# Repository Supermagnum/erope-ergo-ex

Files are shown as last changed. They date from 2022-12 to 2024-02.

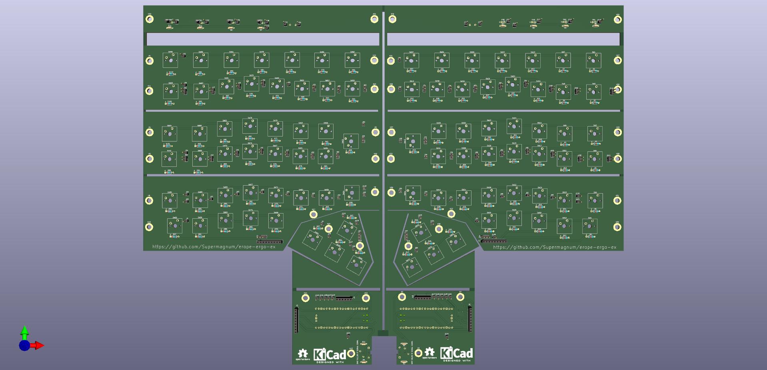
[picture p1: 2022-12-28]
Europe-flex.jpg

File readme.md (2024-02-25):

# Europe-ergo
A 94 key ergonomic,split keyboard, panelized.
Its powered by 2X Raspberry pico and linked with two TRRS jacks.
It uses tht components.

The reset switches, TRRS jacks and raspberry pico's  goes on the reverse side of the Pcb's. 

or:
http://www.keyboard-layout-editor.com/#/gists/50db7ea7b0832342d4c734eb985ec16b

The L1/L2 button is to change from  Norwegian QWERTY to Norwegian Dvorak.

Keycaps:
https://github.com/Supermagnum/Europe-ergo/blob/main/keycaps.jpg

PCBway:
<a href="https://www.pcbway.com/project/shareproject/Europe_ergo_2951aba6.html">PCB from PCBWay</a>

Aisler:
https://aisler.net/p/NEFSAHWJ

Firmware:
[https://github.com/Supermagnum/Europe-ergo/tree/main/Europe_ergo_firmware/europe_ergo](https://github.com/Supermagnum/Europe-ergo/tree/main/ergo-firmware/europe_ergo)

Picture:
https://github.com/Supermagnum/erope-ergo-ex/blob/main/Europe-flex.jpg

All mechanical blueprints as pdf files can be exported from the Freecad file.
Freecad can be found for free here:
https://www.freecadweb.org/

Vial:

https://get.vial.today/

PWM1 to PWM 4 controls LED's ( ON/OFF) based by the active layer, and also caps lock and scroll lock active.

Those and the electrical diagram can be found here:
https://github.com/Supermagnum/Europe-ergo/blob/main/Europe-ergo-PCB/schema/Europe-ergo.pdf
The right side has identical outputs for PWM.

Cherry MX switches should fit the PCB'S.

---------
To do:
Make the cutouts closer to the top and bottoms of the double rows.
Make pcb holders in kicad.
Reduce the number of two pin connectors, and label the connections on the Pcb's.

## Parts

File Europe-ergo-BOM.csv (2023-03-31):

Source: | /mnt/b955457f-512b-4f44-a0f7-8e5f2b78aba2/Europe-ergo/Europe-ergo-PCB/Europe-ergo.kicad_sch
Date: | fr. 31. mars 2023 kl. 15.45 +0200
Tool: | Eeschema 7.0.1-3b83917a11~172~ubuntu22.04.1
Generator: | /usr/share/kicad/plugins/bom_csv_grouped_by_value.py
Component Count: | 234
Collated Components:
Item | Qty | Reference(s) | Value | LibPart | Footprint | Datasheet | DNP | Field4
1 | 94 | D1, D2, D3, D4, D5, D6, D7, D8, D9, D10, D11, D12, D13, D14, D15, D16, D17, D18, D19, D20, D21, D22, D23, D24, D25, D26, D27, D28, D29, D30, D33, D34, D35, D44, D45, D46, D47, D48, D49, D50, D51, D52, D53, D54, D55, D56, D57, D58, D59, D60, D61, D62, D63, D64, D65, D66, D67, D68, D69, D70, D71, D72, D73, D74, D75, D76, D77, D78, D79, D80, D81, D82, D83, D84, D85, D86, D87, D88, D89, D90, D91, D92, D93, D94, D95, D96, D97, D98, D99, D100, D101, D102, D103, D104 | 1N4148 | Diode:1N4148 | Diode_THT:D_DO-35_SOD27_P7.62mm_Horizontal | https://assets.nexperia.com/documents/data-sheet/1N4148_1N4448.pdf
2 | 6 | D31, D32, D36, D37, D38, D43 | LTL-4233 | Device:LED | Diode_THT:D_A-405_P2.54mm_Vertical_AnodeUp | ~
3 | 4 | D39, D40, D41, D42 | LTL-4233 | Device:LED | Diode_THT:D_DO-34_SOD68_P2.54mm_Vertical_KathodeUp | ~
4 | 16 | H1, H2, H3, H4, H5, H6, H7, H8, H9, H10, H11, H12, H13, H14, H15, H16 | MountingHole_Pad | Mechanical:MountingHole_Pad | MountingHole:MountingHole_4.3mm_M4_DIN965_Pad | ~
5 | 2 | J1, J2 | SJ-435107 | Connector:Conn_01x04_Male | sj-conn:CUI_SJ-435107 | ~
6 | 10 | R1, R2, R3, R4, R5, R6, R7, R8, R9, R10 | 330 | Device:R | Resistor_THT:R_Axial_DIN0204_L3.6mm_D1.6mm_P5.08mm_Horizontal | ~
7 | 4 | R11, R12, R13, R14 | 4.7K | Device:R | Resistor_THT:R_Axial_DIN0204_L3.6mm_D1.6mm_P5.08mm_Horizontal | ~
8 | 41 | SW1, SW2, SW3, SW4, SW5, SW6, SW7, SW18, SW19, SW20, SW21, SW22, SW23, SW24, SW34, SW35, SW36, SW37, SW38, SW39, SW50, SW51, SW52, SW53, SW54, SW55, SW64, SW65, SW66, SW67, SW68, SW69, SW71, SW81, SW82, SW83, SW84, SW85, SW86, SW87, SW88 | MX1A-G1NN | pcb-flat-left-rescue:MX-NO-LED-keyboard2-pcb-flat-right-rescue | Button_Switch_Keyboard:SW_Cherry_MX_1.00u_PCB |  |  | arrow-up
9 | 41 | SW8, SW9, SW10, SW11, SW12, SW13, SW14, SW25, SW26, SW27, SW28, SW29, SW30, SW31, SW42, SW43, SW44, SW45, SW46, SW47, SW56, SW57, SW58, SW59, SW60, SW61, SW72, SW74, SW75, SW76, SW77, SW78, SW79, SW89, SW90, SW91, SW92, SW93, SW94, SW95, SW96 | MX1A-G1NN | pcb-flat-right-rescue:MX-NO-LED-keyboard2 | Button_Switch_Keyboard:SW_Cherry_MX_1.00u_PCB |  |  | arrow-up
10 | 2 | SW15, SW16 | 800SP9B6M2RE | Switch:SW_Push | switch:switch_P5.08mm | ~
11 | 6 | SW17, SW33, SW40, SW49, SW63, SW70 | MX1A-G1NN | pcb-flat-left-rescue:MX-NO-LED-keyboard2-pcb-flat-right-rescue | Button_Switch_Keyboard:SW_Cherry_MX_1.50u_PCB
12 | 6 | SW32, SW41, SW48, SW62, SW73, SW80 | MX1A-G1NN | pcb-flat-right-rescue:MX-NO-LED-keyboard2 | Button_Switch_Keyboard:SW_Cherry_MX_1.50u_PCB
13 | 2 | U1, U2 | SC0915 | MCU_RaspberryPi_and_Boards:Pico | MCU_RaspberryPi_and_Boards:RPi_Pico_SMD_TH

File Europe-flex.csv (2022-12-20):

Source: | /home/haaken/98keys-ergo.git/trunk/98keys-split-pcb/98keys-split-pcb.kicad_sch
Date: | lø. 03. des. 2022 kl. 18.18 +0100
Tool: | Eeschema 6.0.9-8da3e8f707~117~ubuntu20.04.1
Generator: | /usr/share/kicad/plugins/bom_csv_grouped_by_value_with_fp.py
Component Count: | 230
Ref | Qnty | Value | Cmp name | Footprint | Description | Vendor
D1, D2, D3, D4, D5, D6, D7, D8, D9, D10, D11, D12, D13, D14, D15, D16, D17, D18, D19, D20, D21, D22, D23, D24, D25, D26, D27, D28, D29, D30, D31, D32, D33, D34, D35, D36, D37, D38, D39, D40, D41, D42, D43, D44, D45, D46, D47, D56, D57, D58, D59, D60, D61, D62, D63, D64, D65, D66, D67, D68, D69, D70, D71, D72, D73, D74, D75, D76, D77, D78, D79, D80, D81, D82, D83, D84, D85, D86, D87, D88, D89, D90, D91, D92, D93, D94, D95, D96, D97, D98, D99, D100, D101, D102, | 94 | 1N4148 | 1N4148 | Diode_THT:D_DO-35_SOD27_P7.62mm_Horizontal | 100V 0.15A standard switching diode, DO-35
D48, D49, D50, D51, | 4 | LED | LED | Diode_THT:D_DO-34_SOD68_P2.54mm_Vertical_KathodeUp | Light emitting diode
D52, D53, D54, D55, | 4 | LTL-4233 | LED | Diode_THT:D_A-405_P2.54mm_Vertical_AnodeUp | Light emitting diode
H1, H2, H3, H4, H5, H6, H7, H8, H9, H10, H11, H12, H13, H14, H15, H16, | 16 | MountingHole_Pad | MountingHole_Pad | MountingHole:MountingHole_4.3mm_M4_DIN965_Pad | Mounting Hole with connection
J1, | 1 | Conn_01x04_Male/I2C | Conn_01x04_Male | Connector_Audio:Jack_3.5mm_CUI_SJ1-43514_Horizontal | Generic connector, single row, 01x04, script generated (kicad-library-utils/schlib/autogen/connector/)
J2, | 1 | Conn_01x04_Male | Conn_01x04_Male | Connector_Audio:Jack_3.5mm_CUI_SJ1-43514_Horizontal | Generic connector, single row, 01x04, script generated (kicad-library-utils/schlib/autogen/connector/)
R1, R2, R4, R6, R7, R8, R10, R12, | 8 | 330 | R | Resistor_THT:R_Axial_DIN0204_L3.6mm_D1.6mm_P5.08mm_Horizontal | Resistor
R3, R5, R9, R11, | 4 | 4.7K | R | Resistor_THT:R_Axial_DIN0204_L3.6mm_D1.6mm_P5.08mm_Horizontal | Resistor
SW1, SW6, SW7, SW8, SW9, SW10, SW11, SW12, SW13, SW14, SW15, SW16, SW17, SW18, SW19, SW20, SW21, SW22, SW23, SW24, SW25, SW26, SW27, SW28, SW29, SW30, SW31, SW32, SW33, SW34, SW35, SW36, SW37, SW38, SW39, SW40, SW41, SW42, SW45, SW46, SW47, SW50, SW51, SW52, SW55, SW56, SW57, SW58, SW59, SW60, SW61, SW62, SW63, SW64, SW65, SW66, SW67, SW68, SW69, SW70, SW71, SW72, SW73, SW74, SW75, SW76, SW77, SW78, SW79, SW80, SW81, SW82, SW83, SW84, SW85, SW86, SW87, SW88, SW89, SW90, SW92, SW96, | 82 | MX-NO-LED | MX-NO-LED-keyboard2-pcb-flat-right-rescue | Button_Switch_Keyboard:SW_Cherry_MX_1.00u_PCB
SW2, SW3, SW4, SW5, SW43, SW44, SW53, SW54, SW91, SW93, SW94, SW95, | 12 | MX-NO-LED | MX-NO-LED-keyboard2-pcb-flat-right-rescue | Button_Switch_Keyboard:SW_Cherry_MX_1.50u_PCB
SW48, SW49, | 2 | SW_Push | SW_Push | switch:switch_P5.08mm | Push button switch, generic, two pins
U1, U2, | 2 | Pico | Pico | MCU_RaspberryPi_and_Boards:RPi_Pico_SMD_TH

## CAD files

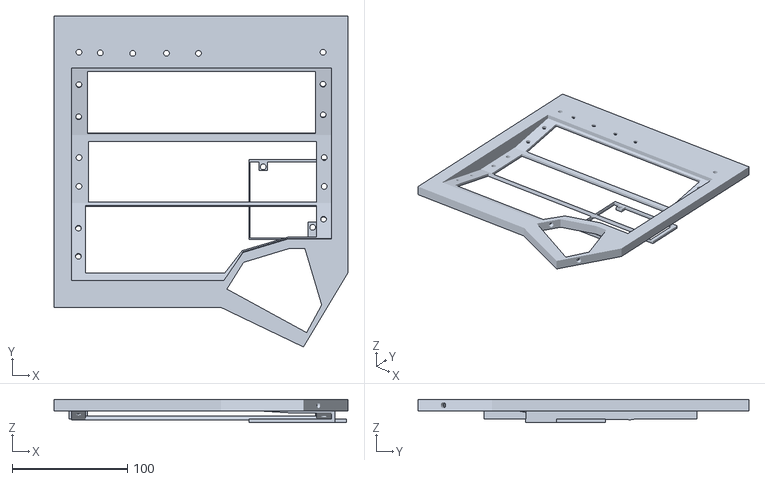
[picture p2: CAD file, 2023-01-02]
Mechanical/holder-left.stl
255.0 x 287.5 x 20.0

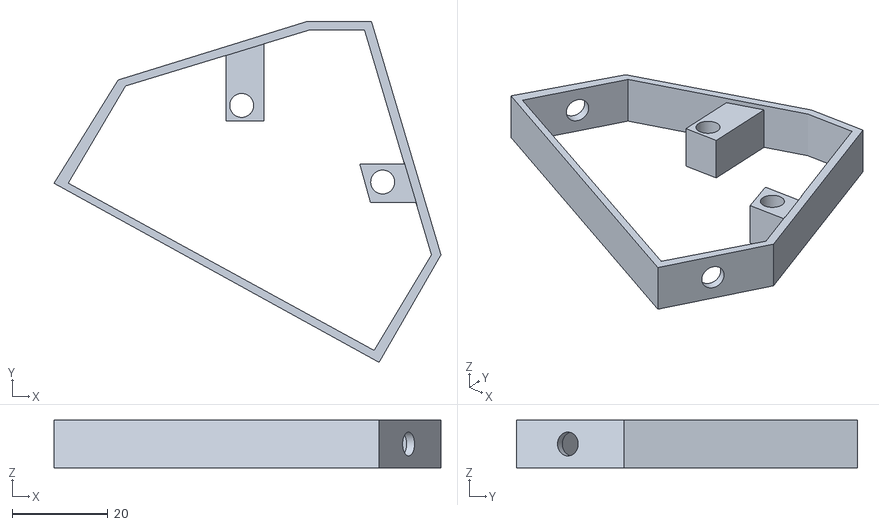
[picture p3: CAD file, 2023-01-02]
Mechanical/holder-thumb.stl
81.0 x 71.3 x 10.0

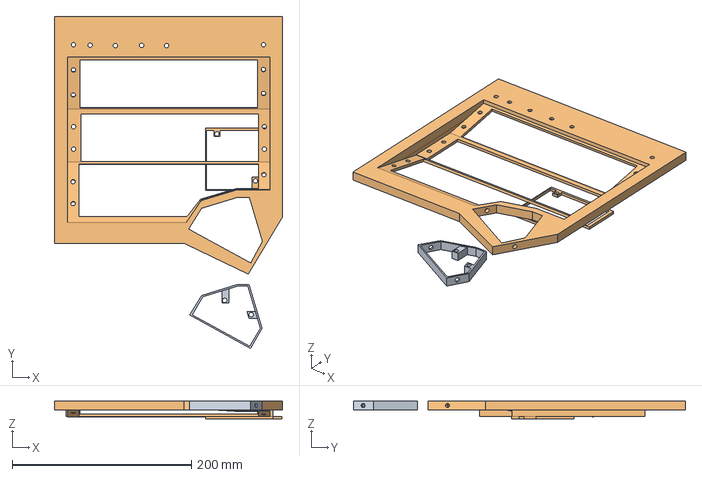
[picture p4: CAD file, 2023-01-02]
Mechanical/holder.FCStd
255.0 x 370.5 x 20.0 mm

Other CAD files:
Mechanical/holder-right.stl
Mechanical/holders.blend

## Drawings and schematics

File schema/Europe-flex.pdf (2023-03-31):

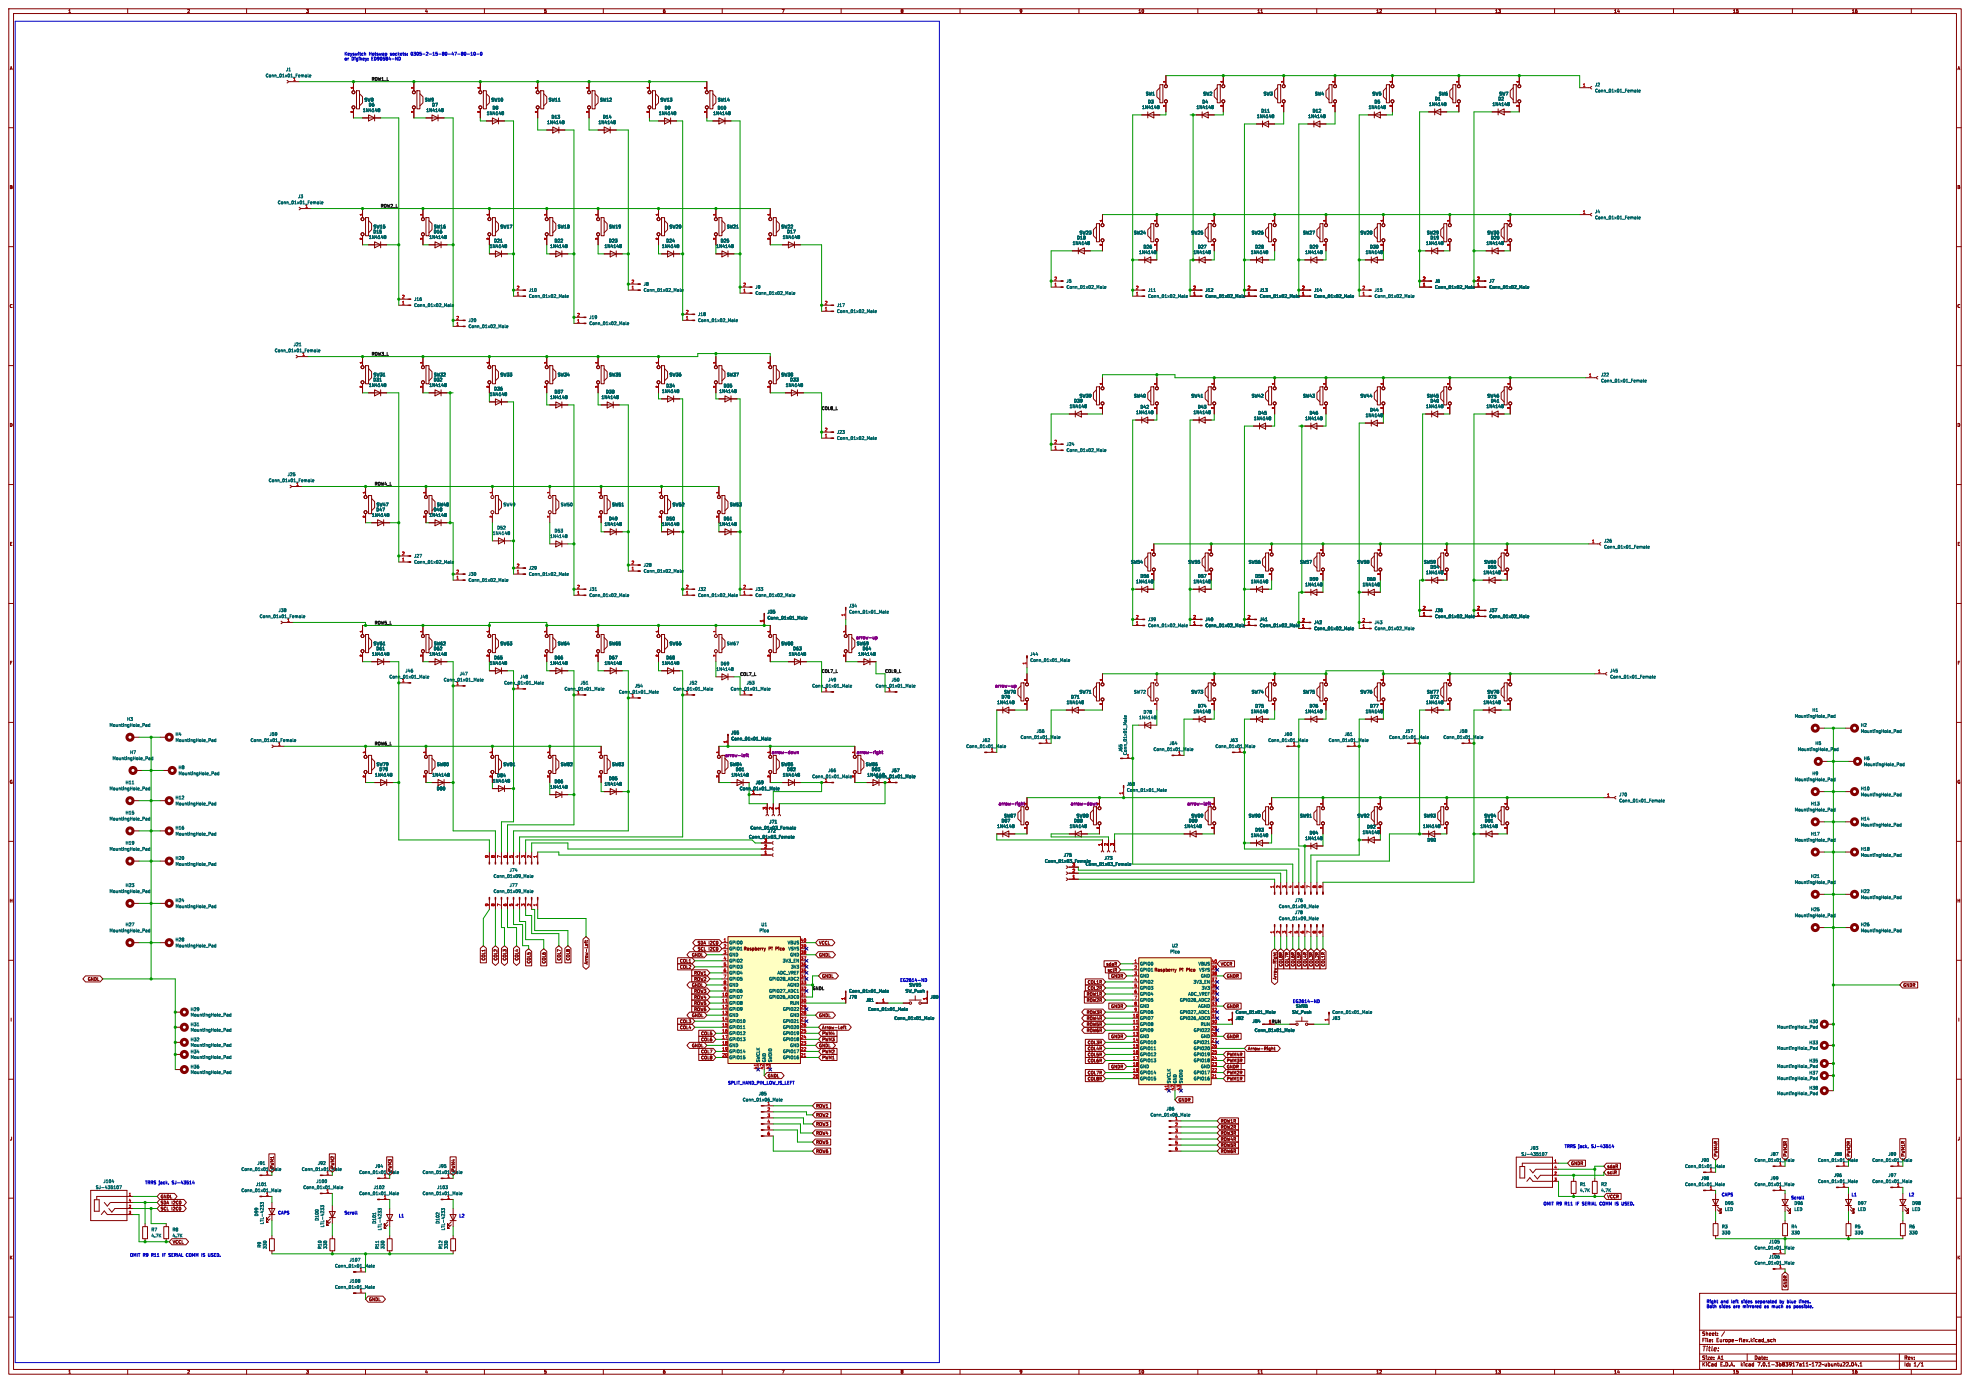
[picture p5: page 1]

PWM3 PWM1 PWM2 GNDL PWM4 GNDL VCCL GNDL PWM3

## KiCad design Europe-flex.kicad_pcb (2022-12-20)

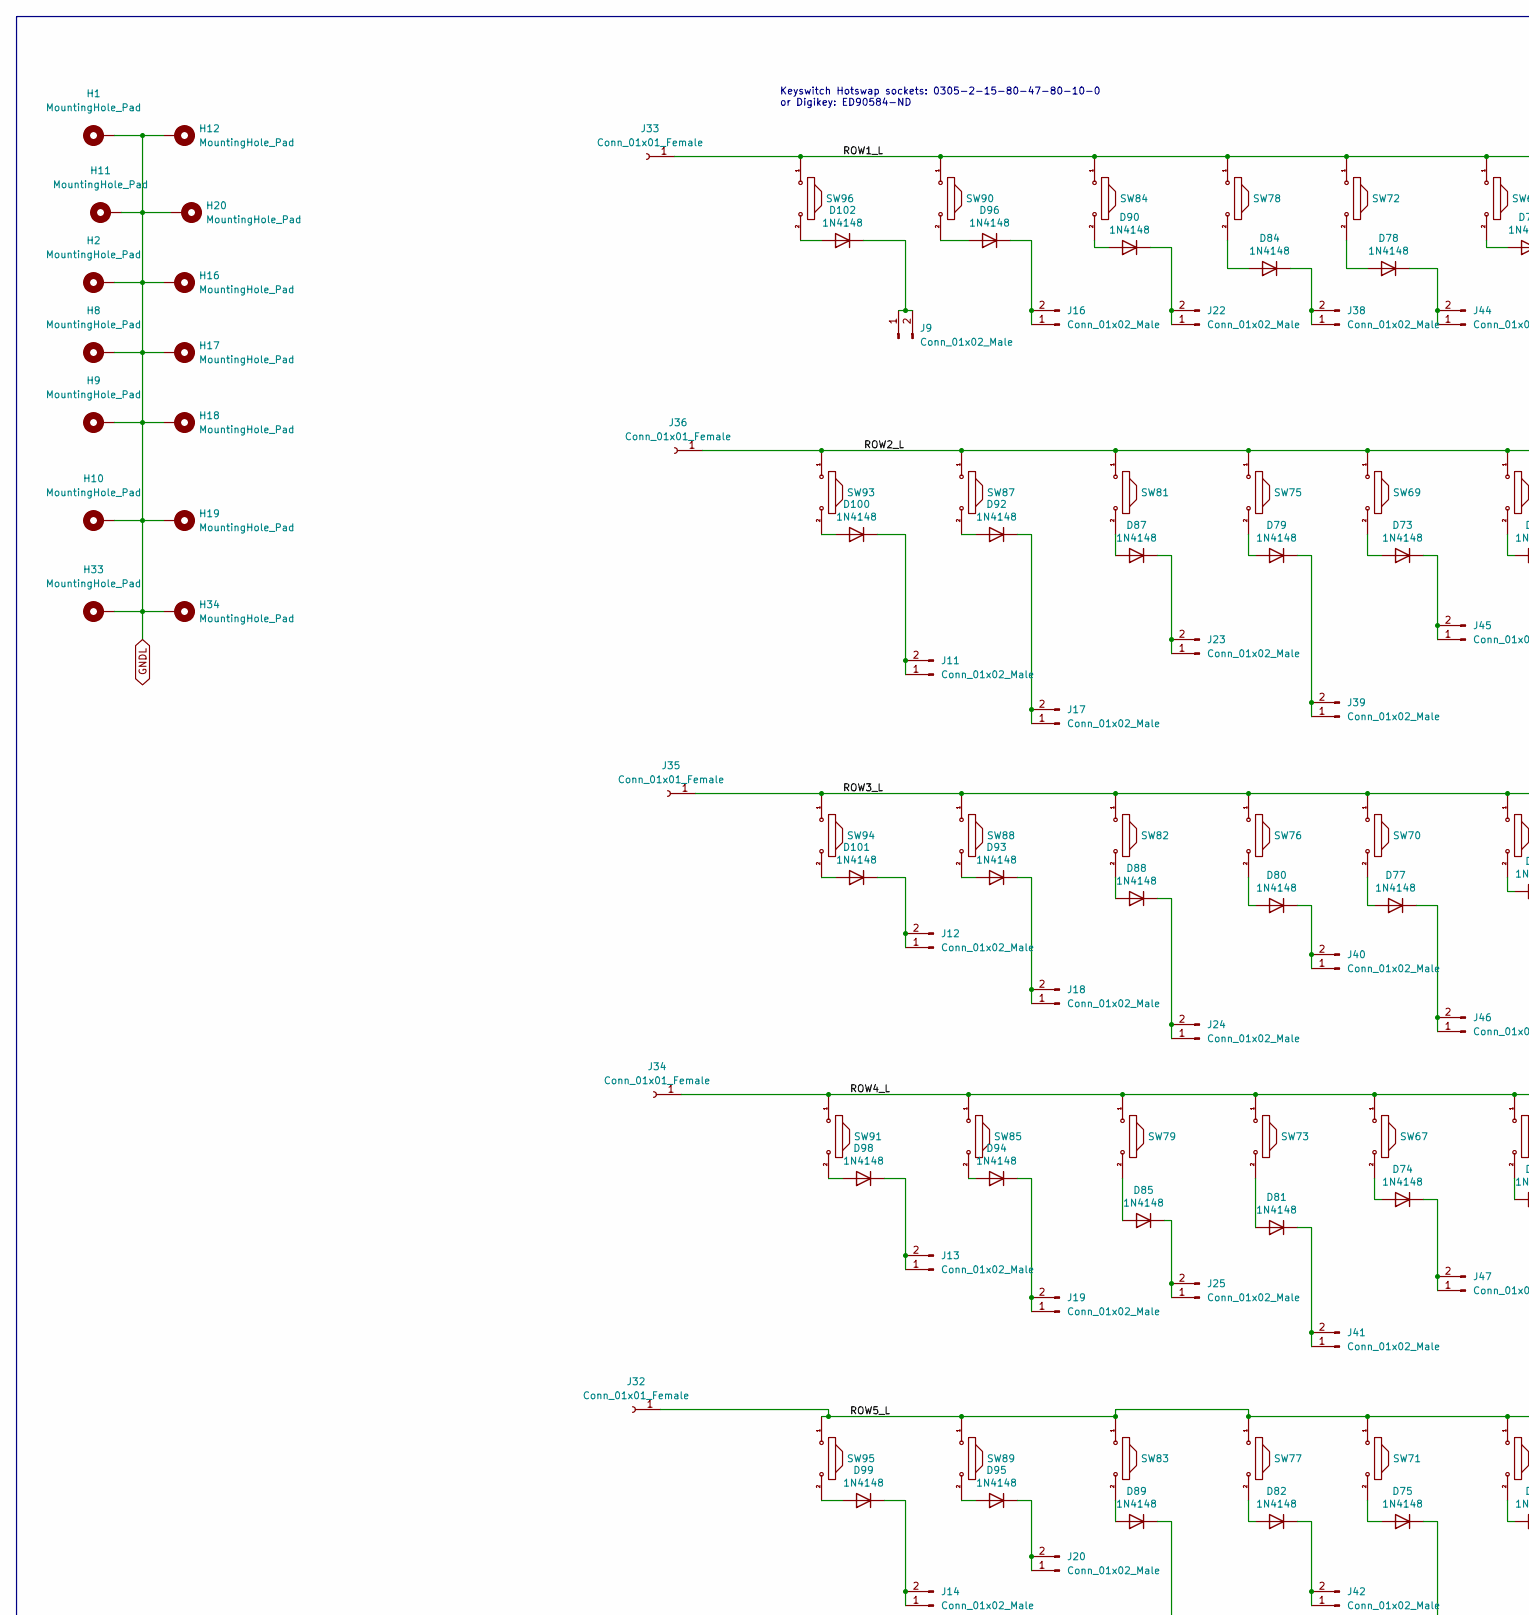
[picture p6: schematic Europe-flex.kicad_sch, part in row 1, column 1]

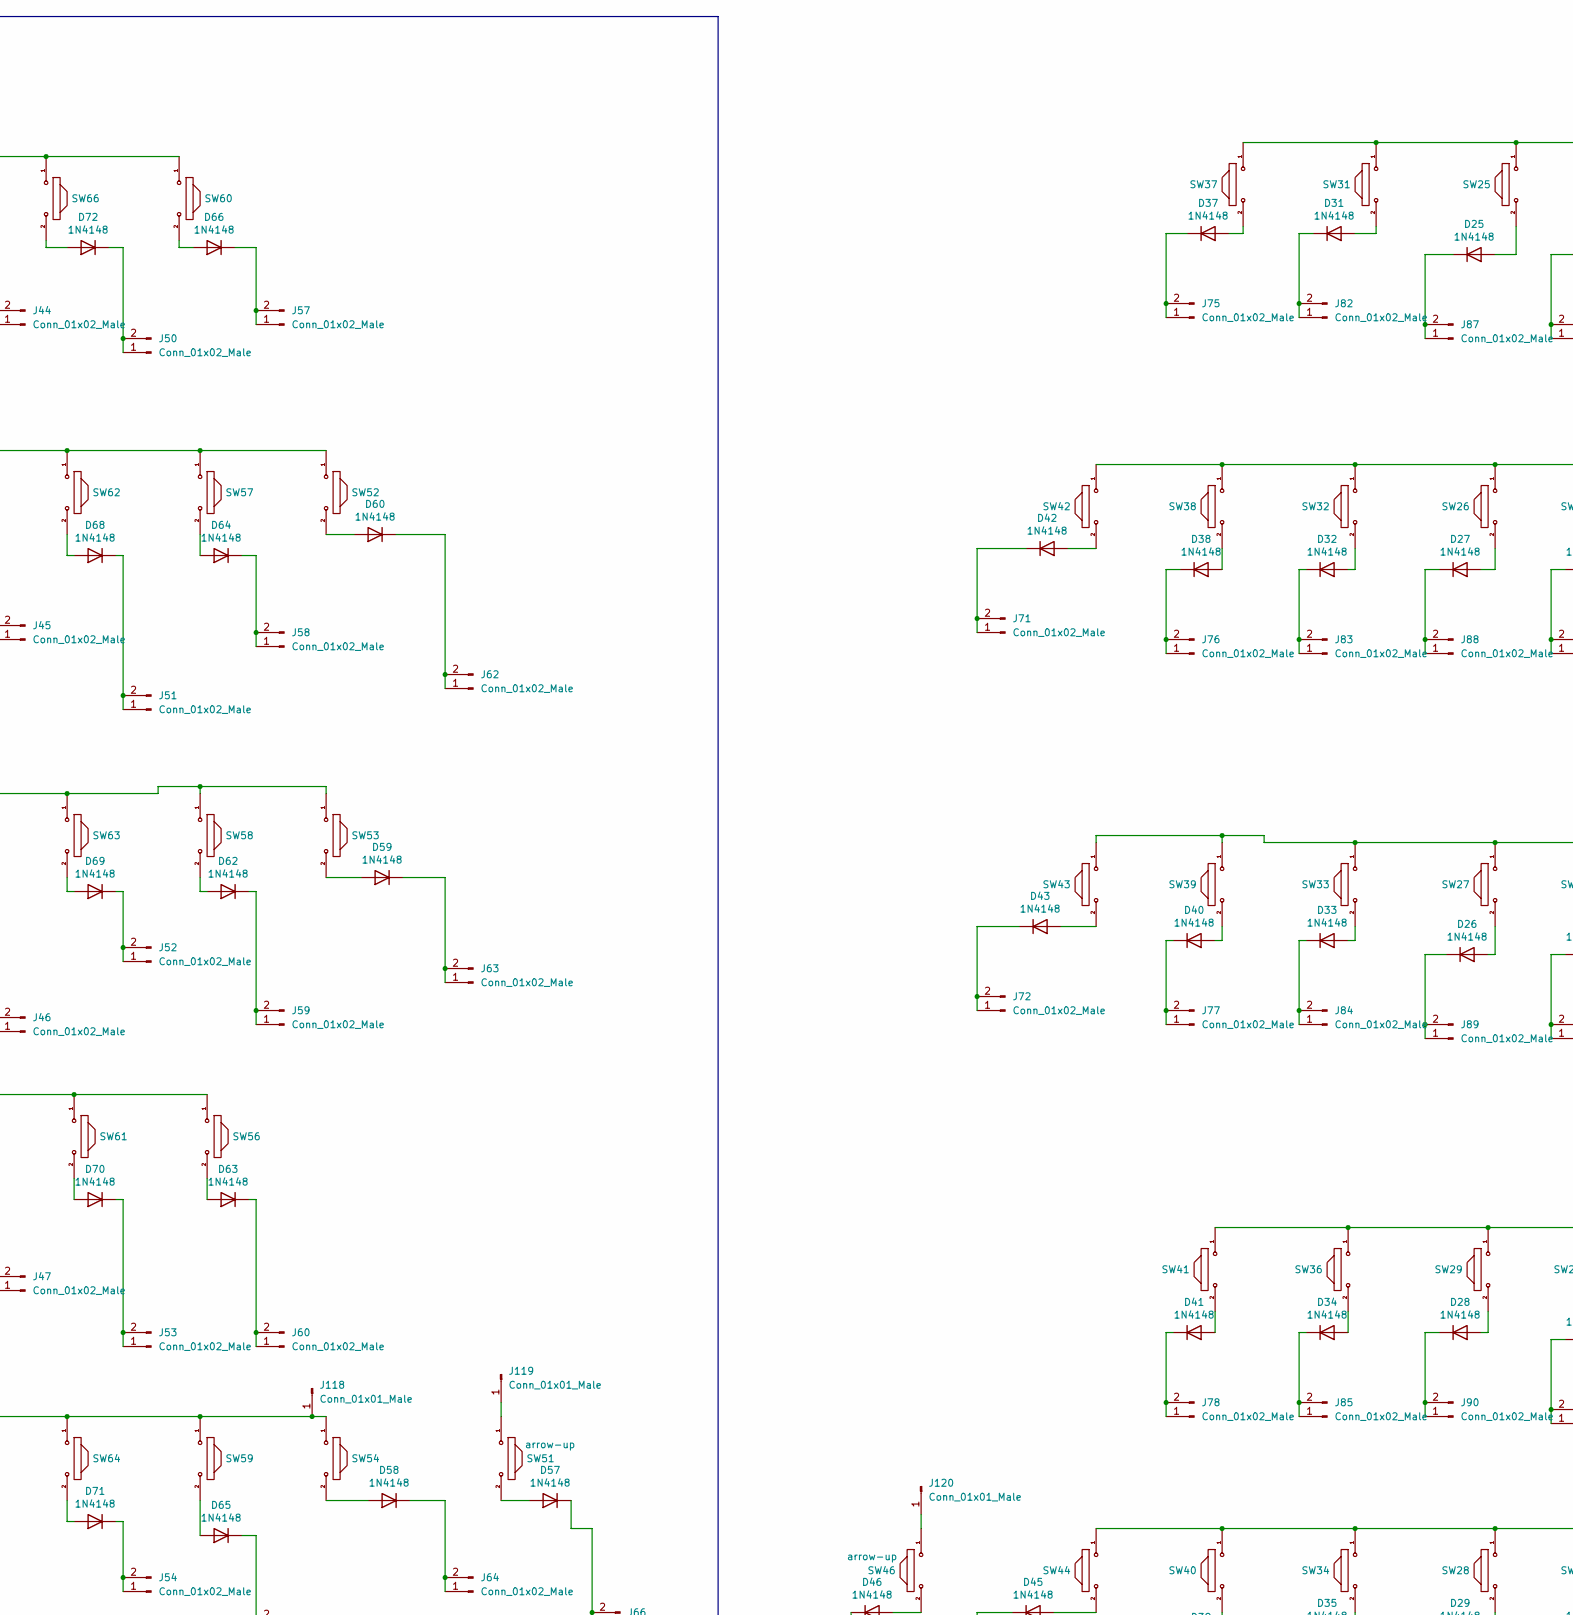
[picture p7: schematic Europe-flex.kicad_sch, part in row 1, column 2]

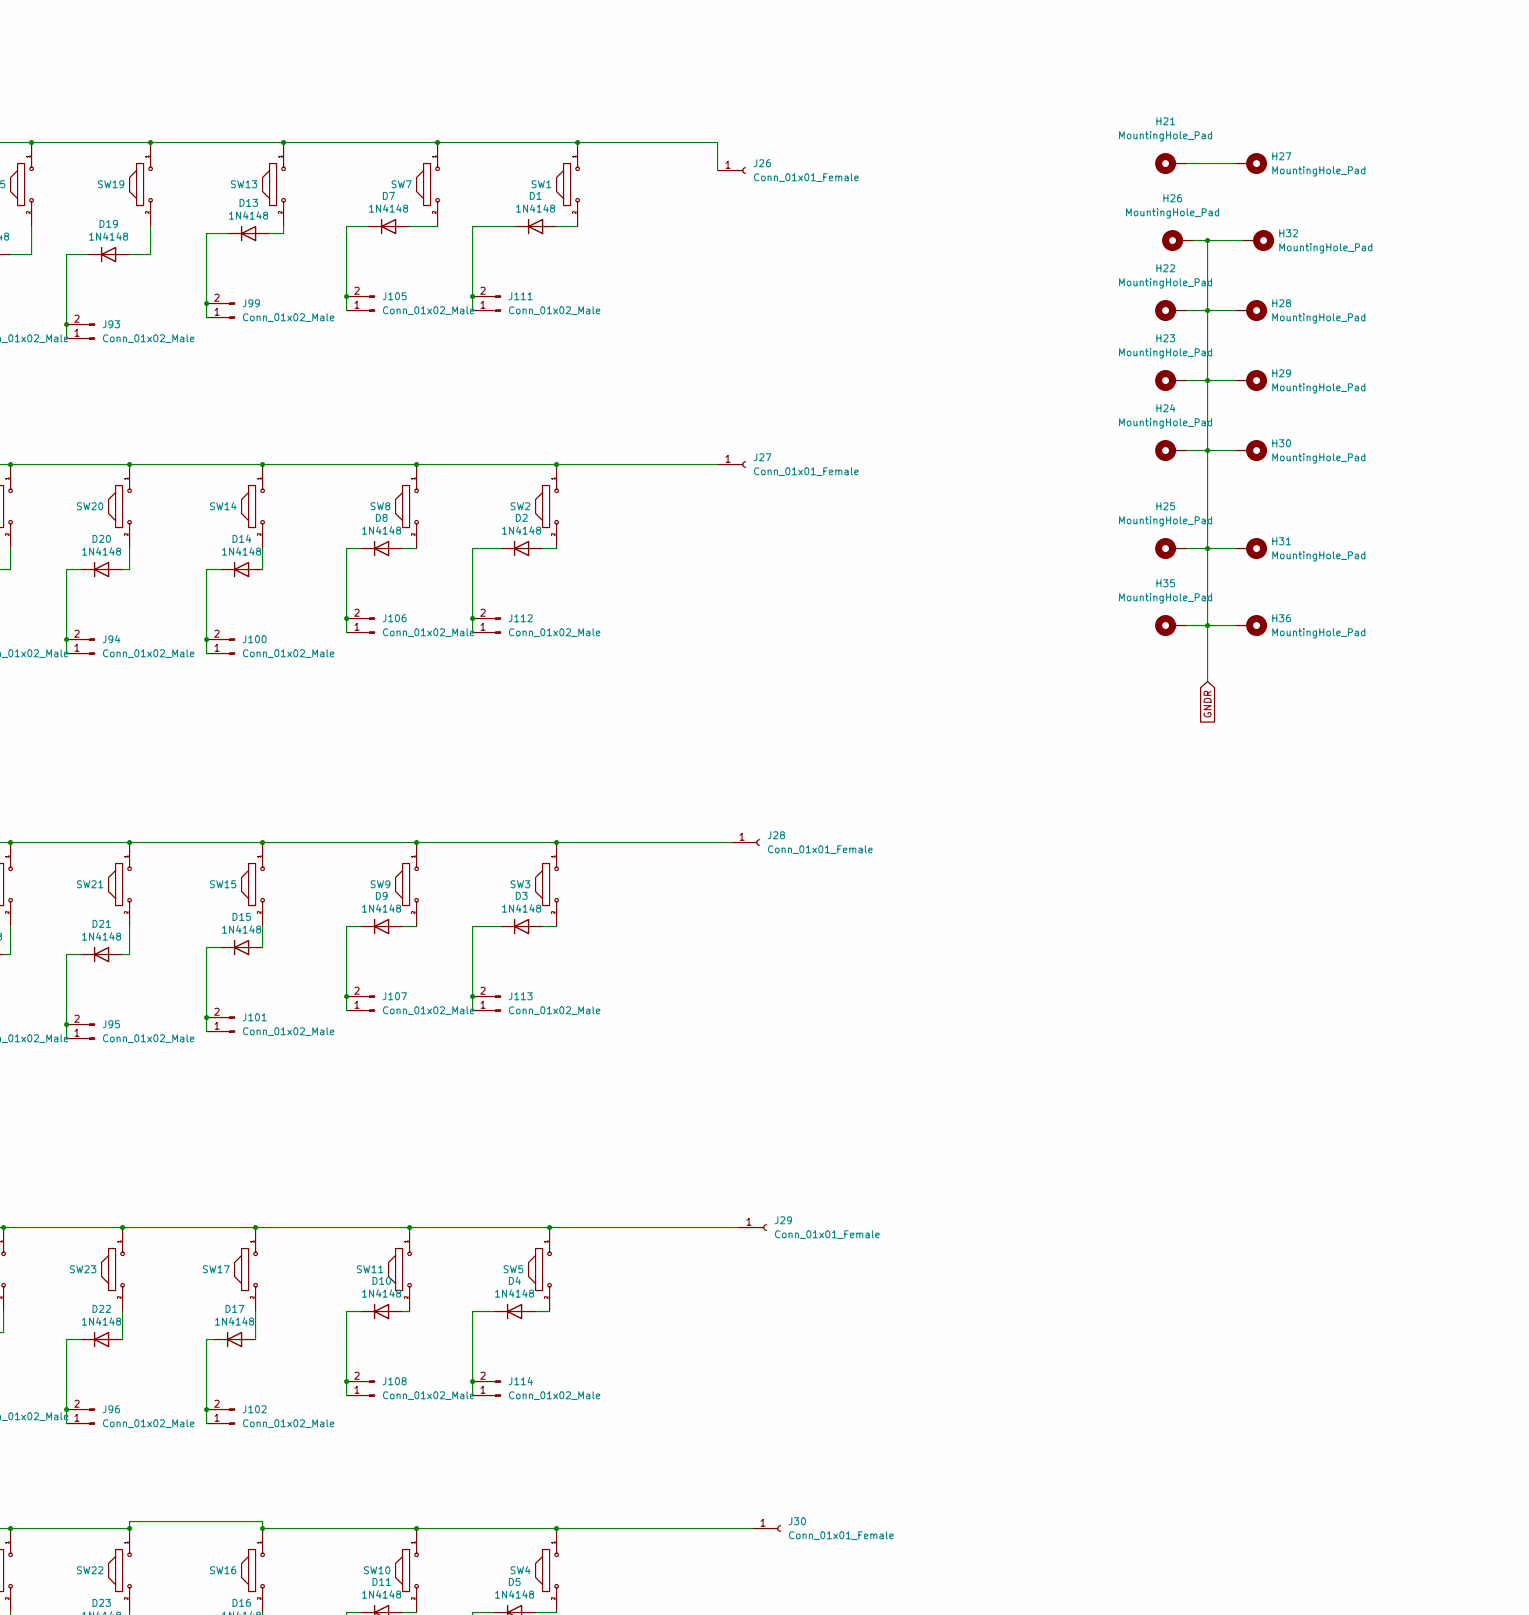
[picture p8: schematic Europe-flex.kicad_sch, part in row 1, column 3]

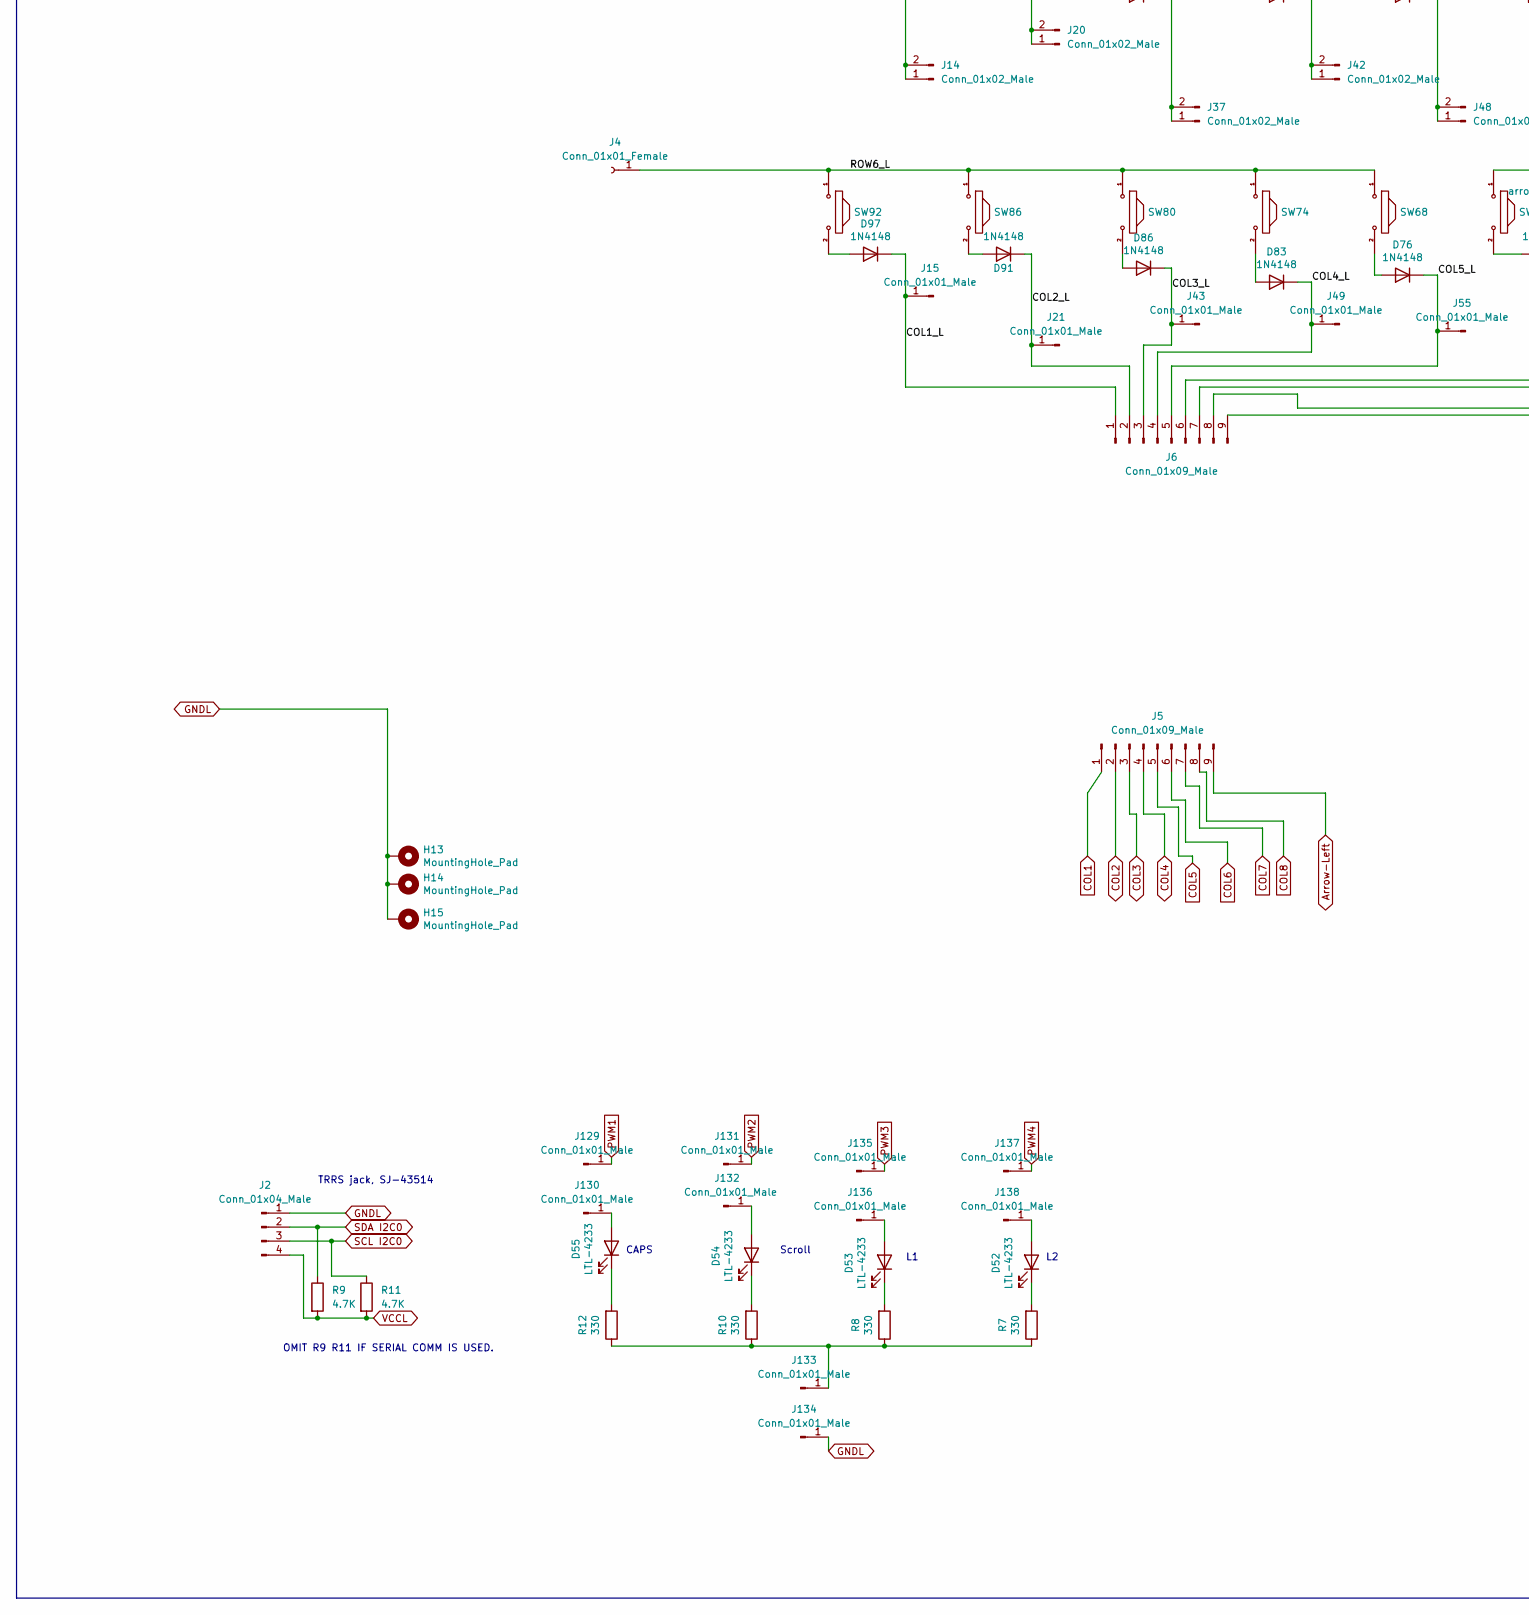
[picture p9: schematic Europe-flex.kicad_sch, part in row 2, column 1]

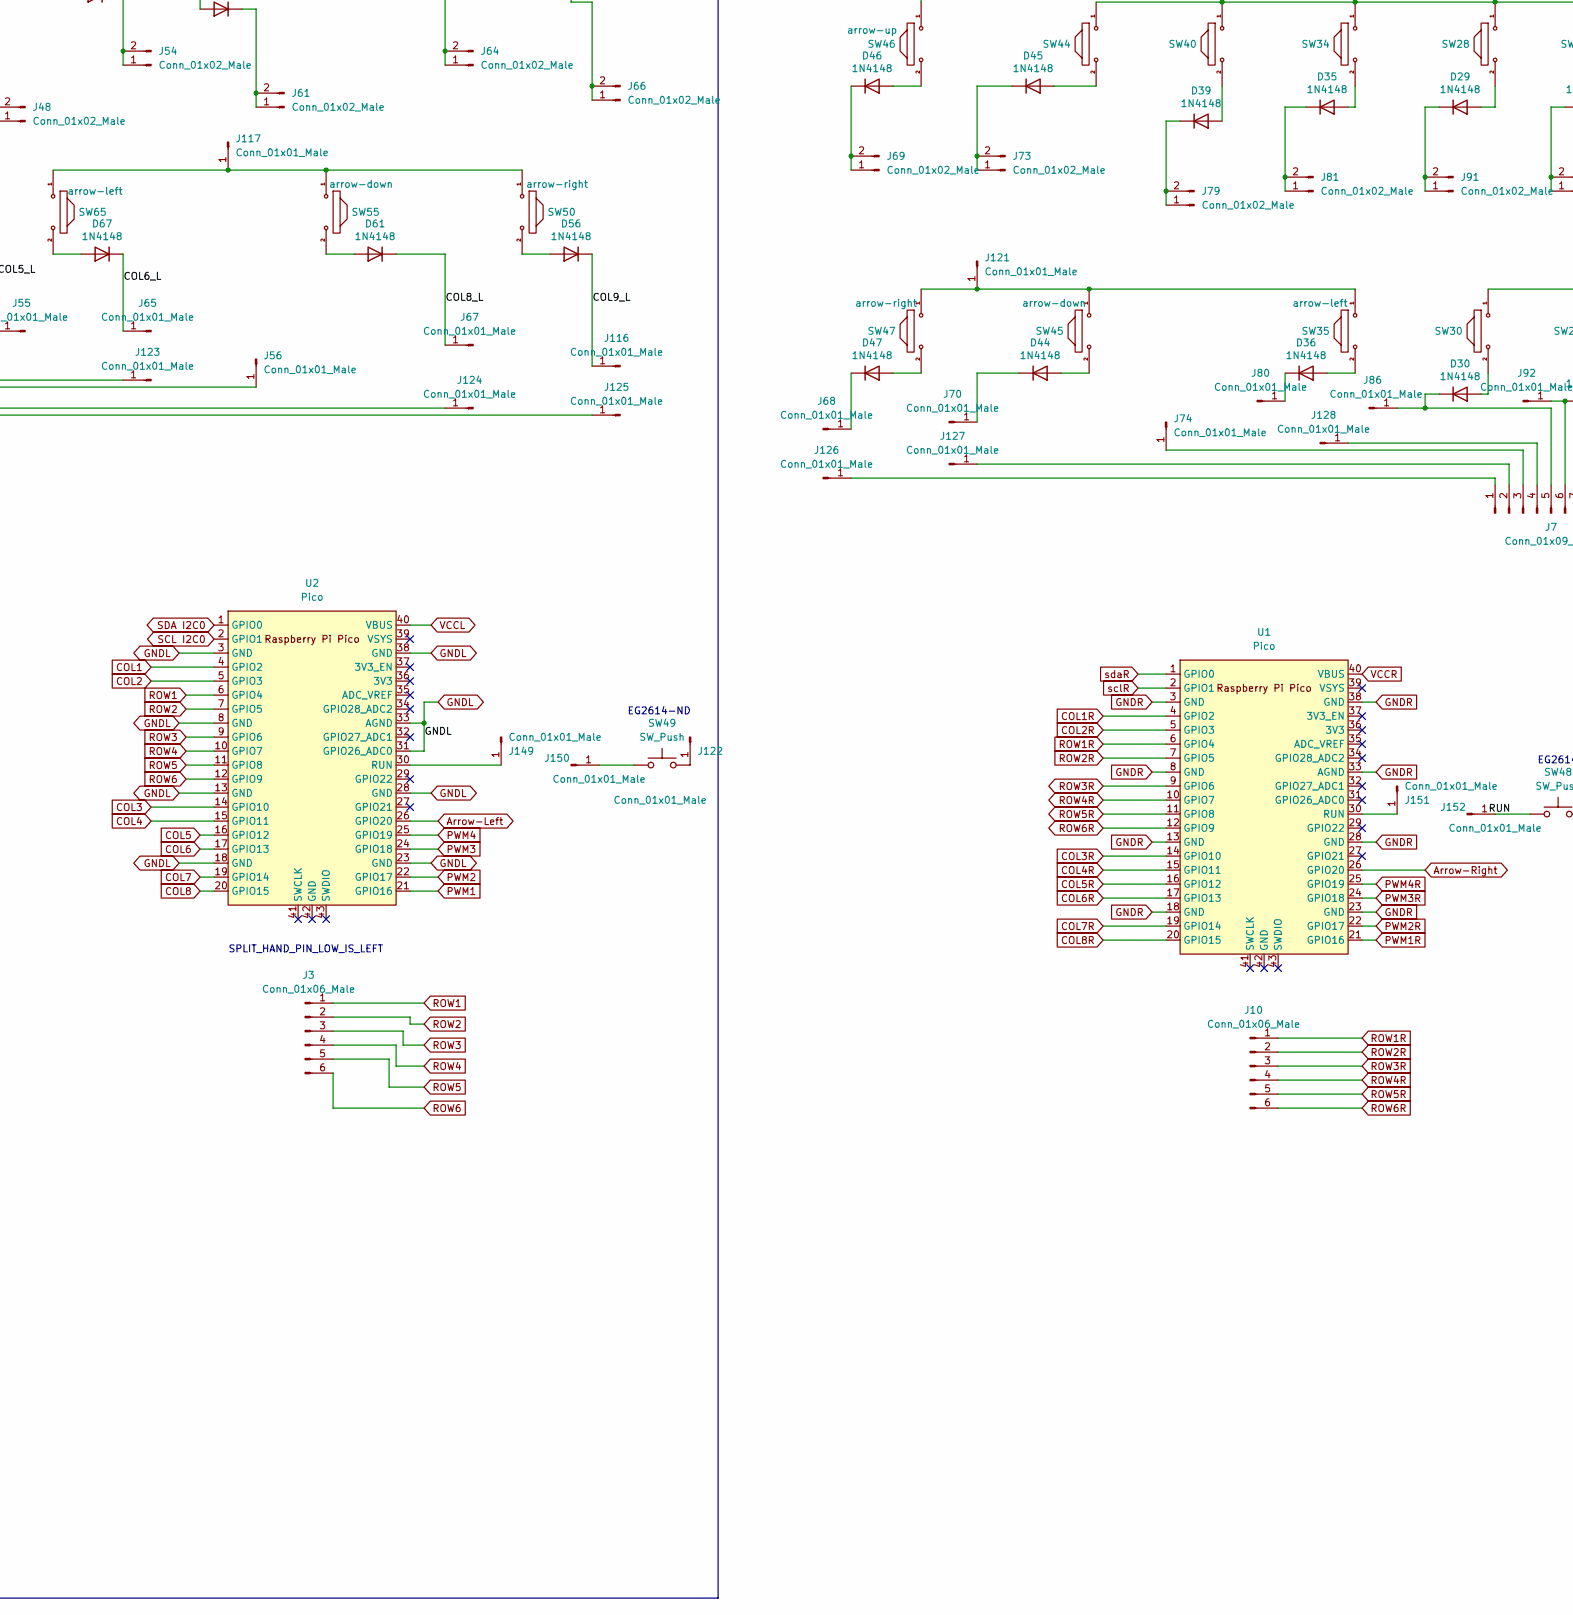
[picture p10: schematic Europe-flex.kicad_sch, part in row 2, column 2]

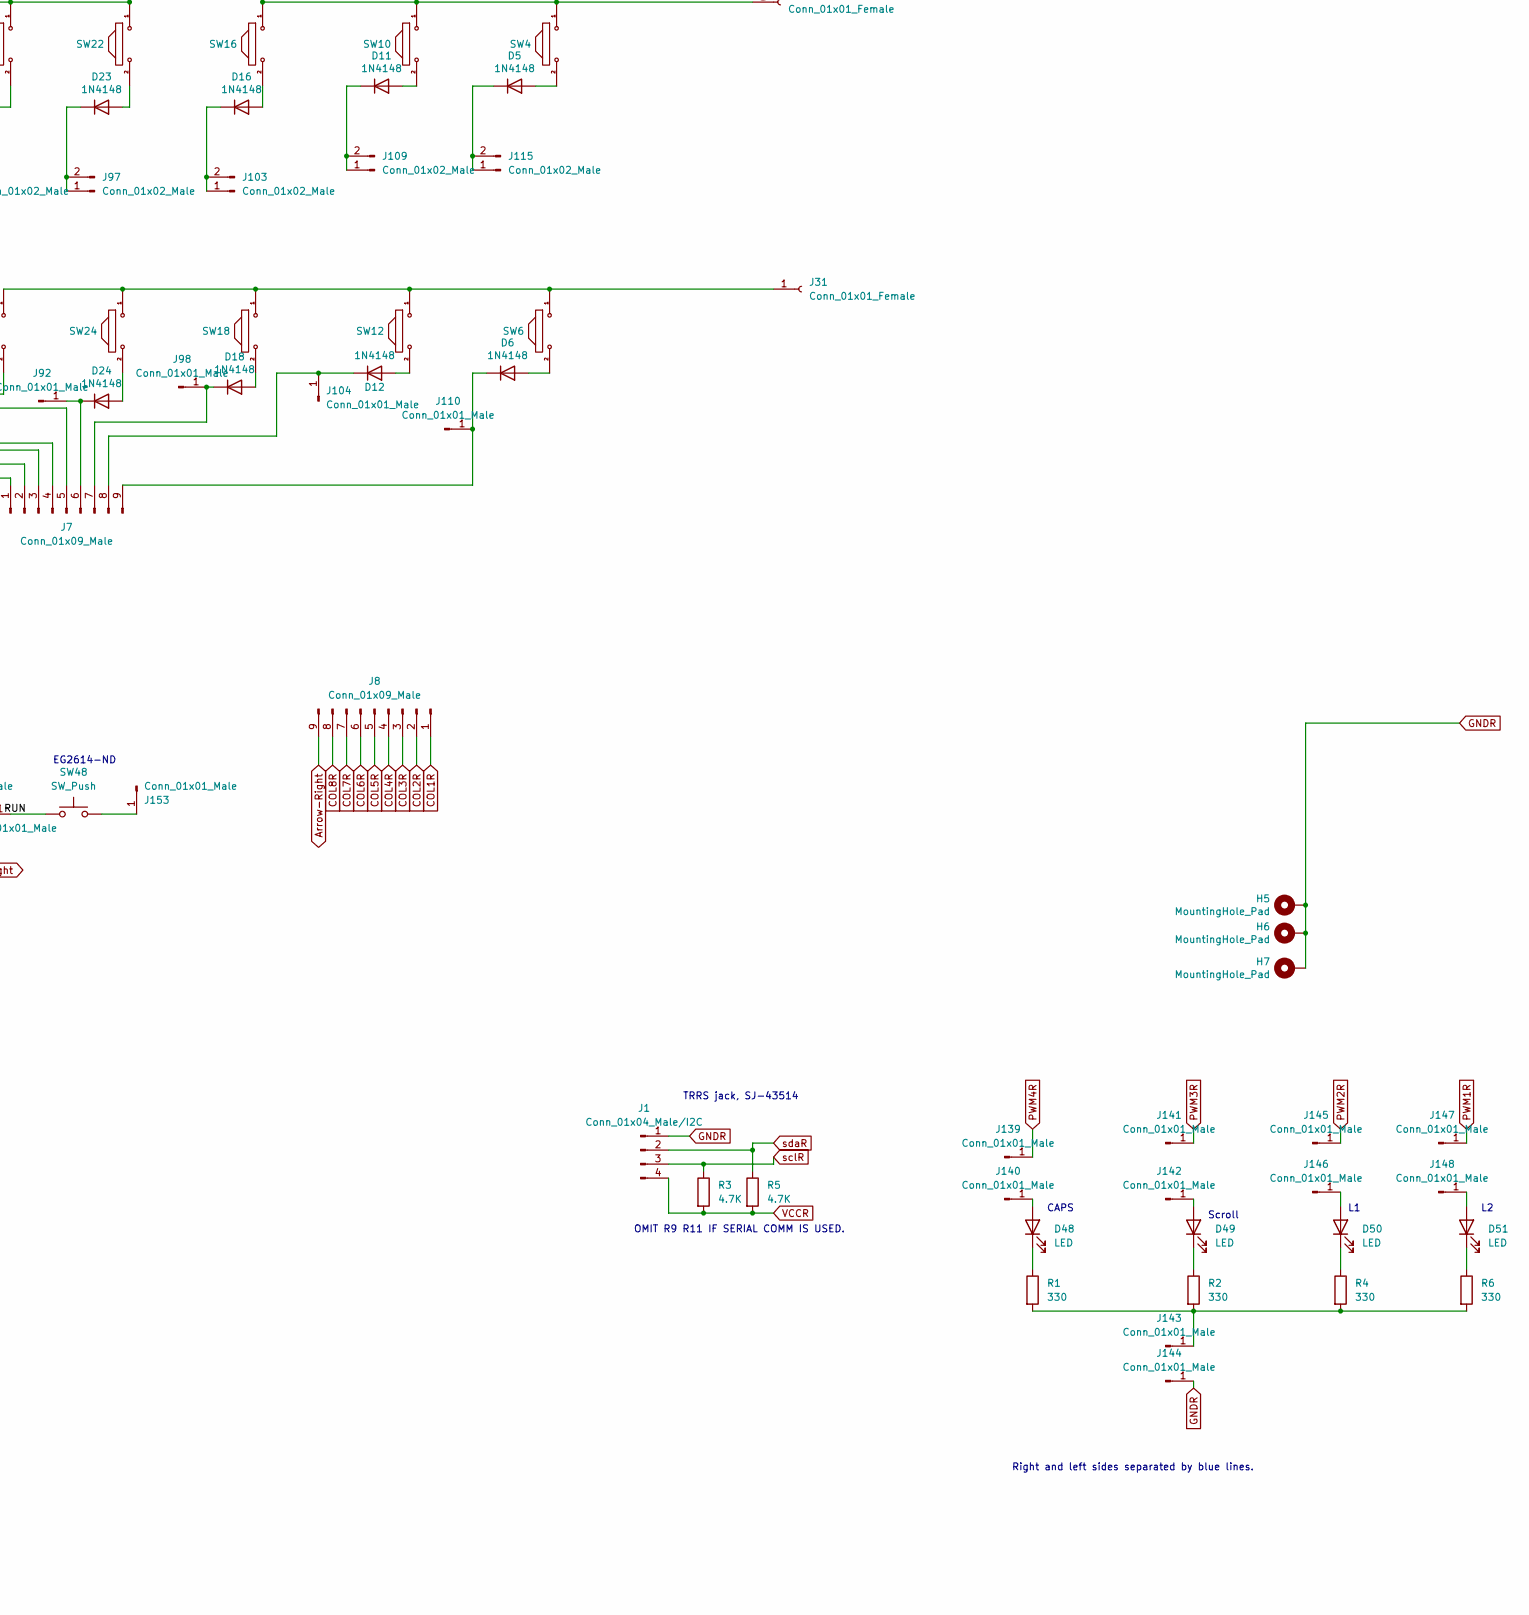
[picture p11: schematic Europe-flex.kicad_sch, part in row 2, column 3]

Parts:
D1, D2, D3, D4, D5, D6, D7, D8, D9, D10, D11, D12, D13, D14, D15, D16, D17, D18, D19, D20, D21, D22, D23, D24, D25, D26, D27, D28, D29, D30, D31, D32, D33, D34, D35, D36, D37, D38, D39, D40, D41, D42, D43, D44, D45, D46, D47, D56, D57, D58, D59, D60, D61, D62, D63, D64, D65, D66, D67, D68, D69, D70, D71, D72, D73, D74, D75, D76, D77, D78, D79, D80, D81, D82, D83, D84, D85, D86, D87, D88, D89, D90, D91, D92, D93, D94, D95, D96, D97, D98, D99, D100, D101, D102: 1N4148; D_DO-35_SOD27_P7.62mm_Horizontal
D48, D49, D50, D51: LED; D_DO-34_SOD68_P2.54mm_Vertical_KathodeUp
D52, D53, D54, D55: LTL-4233; D_A-405_P2.54mm_Vertical_AnodeUp
H1, H2, H5, H6, H7, H8, H9, H10, H11, H12, H13, H14, H15, H16, H17, H18, H19, H20, H21, H22, H23, H24, H25, H26, H27, H28, H29, H30, H31, H32, H33, H34, H35, H36: MountingHole_Pad; MountingHole_4.3mm_M4_DIN965_Pad
J1: Conn_01x04_Male/I2C; CUI_SJ-43514
J2: Conn_01x04_Male; CUI_SJ-43514
J3, J10: Conn_01x06_Male; PinSocket_1x06_P2.54mm_Vertical
J4, J26, J27, J28, J29, J30, J31, J32, J33, J34, J35, J36: Conn_01x01_Female; PinSocket_1x01_P2.54mm_Vertical
J5, J6, J7, J8: Conn_01x09_Male; PinSocket_1x09_P2.54mm_Vertical
J9, J11, J12, J13, J14, J16, J17, J18, J19, J20, J22, J23, J24, J25, J37, J38, J39, J40, J41, J42, J44, J45, J46, J47, J48, J50, J51, J52, J53, J54, J57, J58, J59, J60, J61, J62, J63, J64, J66, J69, J71, J72, J73, J75, J76, J77, J78, J79, J81, J82, J83, J84, J85, J87, J88, J89, J90, J91, J93, J94, J95, J96, J97, J99, J100, J101, J102, J103, J105, J106, J107, J108, J109, J111, J112, J113, J114, J115: Conn_01x02_Male; PinHeader_1x02_P2.54mm_Vertical
J15, J21, J43, J49, J55, J56, J65, J67, J68, J70, J74, J80, J86, J92, J98, J104, J110, J116, J117, J118, J119, J120, J121, J122, J123, J124, J125, J126, J127, J128, J129, J130, J131, J132, J133, J134, J135, J136, J137, J138, J139, J140, J141, J142, J143, J144, J145, J146, J147, J148, J149, J150, J151, J152, J153: Conn_01x01_Male; PinHeader_1x01_P2.54mm_Vertical
R1, R2, R4, R6, R7, R8, R10, R12: 330; R_Axial_DIN0204_L3.6mm_D1.6mm_P5.08mm_Horizontal
R3, R5, R9, R11: 4.7K; R_Axial_DIN0204_L3.6mm_D1.6mm_P5.08mm_Horizontal
SW1, SW6, SW7, SW8, SW9, SW10, SW11, SW12, SW13, SW14, SW15, SW16, SW17, SW18, SW19, SW20, SW21, SW22, SW23, SW24, SW25, SW26, SW27, SW28, SW29, SW30, SW31, SW32, SW33, SW34, SW35, SW36, SW37, SW38, SW39, SW40, SW41, SW42, SW45, SW46, SW47, SW50, SW51, SW52, SW55, SW56, SW57, SW58, SW59, SW60, SW61, SW62, SW63, SW64, SW65, SW66, SW67, SW68, SW69, SW70, SW71, SW72, SW73, SW74, SW75, SW76, SW77, SW78, SW79, SW80, SW81, SW82, SW83, SW84, SW85, SW86, SW87, SW88, SW89, SW90, SW92, SW96: MX-NO-LED; SW_Cherry_MX_1.00u_PCB
SW2, SW3, SW4, SW5, SW43, SW44, SW53, SW54, SW91, SW93, SW94, SW95: MX-NO-LED; SW_Cherry_MX_1.50u_PCB
SW48, SW49: SW_Push; switch_P5.08mm
U1, U2: Pico; RPi_Pico_SMD_TH

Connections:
/COL1_L: D97.1 (K), J6.1, J15.1
/COL2_L: D91.1 (K), J6.2, J21.1
/COL3_L: D86.1 (K), J6.3, J43.1
/COL4_L: D83.1 (K), J6.4, J49.1
/COL5_L: D76.1 (K), J6.5, J55.1
/COL6_L: D67.1 (K), J65.1
/COL8_L: D61.1 (K), J67.1
/COL9_L: D56.1 (K), J116.1
/ROW1_L: J33.1, SW60.1, SW66.1, SW72.1, SW78.1, SW84.1, SW90.1, SW96.1
/ROW2_L: J36.1, SW52.1, SW57.1, SW62.1, SW69.1, SW75.1, SW81.1, SW87.1, SW93.1
/ROW3_L: J35.1, SW53.1, SW58.1, SW63.1, SW70.1, SW76.1, SW82.1, SW88.1, SW94.1
/ROW4_L: J34.1, SW56.1, SW61.1, SW67.1, SW73.1, SW79.1, SW85.1, SW91.1
/ROW5_L: J32.1, J118.1, SW54.1, SW59.1, SW64.1, SW71.1, SW77.1, SW83.1, SW89.1, SW95.1
/ROW6_L: J4.1, SW68.1, SW74.1, SW80.1, SW86.1, SW92.1
Arrow-Left: J5.9, U2.26 (GPIO20)
Arrow-Right: J8.9, U1.26 (GPIO20)
COL1: J5.1, U2.4 (GPIO2)
COL1R: J8.1, U1.4 (GPIO2)
COL2: J5.2, U2.5 (GPIO3)
COL2R: J8.2, U1.5 (GPIO3)
COL3: J5.3, U2.14 (GPIO10)
COL3R: J8.3, U1.14 (GPIO10)
COL4: J5.4, U2.15 (GPIO11)
COL4R: J8.4, U1.15 (GPIO11)
COL5: J5.5, U2.16 (GPIO12)
COL5R: J8.5, U1.16 (GPIO12)
COL6: J5.6, U2.17 (GPIO13)
COL6R: J8.6, U1.17 (GPIO13)
COL7: J5.7, U2.19 (GPIO14)
COL7R: J8.7, U1.19 (GPIO14)
COL8: J5.8, U2.20 (GPIO15)
COL8R: J8.8, U1.20 (GPIO15)
unnamed: D1.1 (K), J111.1, J111.2
unnamed: D1.2 (A), SW1.2
unnamed: D2.1 (K), J112.1, J112.2
unnamed: D2.2 (A), SW2.2
unnamed: D3.1 (K), J113.1, J113.2
unnamed: D3.2 (A), SW3.2
unnamed: D4.1 (K), J114.1, J114.2
unnamed: D4.2 (A), SW5.2
unnamed: D5.1 (K), J115.1, J115.2
unnamed: D5.2 (A), SW4.2
unnamed: D6.1 (K), J7.9, J110.1
unnamed: D6.2 (A), SW6.2
unnamed: D7.1 (K), J105.1, J105.2
unnamed: D7.2 (A), SW7.2
unnamed: D8.1 (K), J106.1, J106.2
unnamed: D8.2 (A), SW8.2
unnamed: D9.1 (K), J107.1, J107.2
unnamed: D9.2 (A), SW9.2
unnamed: D10.1 (K), J108.1, J108.2
unnamed: D10.2 (A), SW11.2
unnamed: D11.1 (K), J109.1, J109.2
unnamed: D11.2 (A), SW10.2
unnamed: D12.1 (K), J7.8, J104.1
unnamed: D12.2 (A), SW12.2
unnamed: D13.1 (K), J99.1, J99.2
unnamed: D13.2 (A), SW13.2
unnamed: D14.1 (K), J100.1, J100.2
unnamed: D14.2 (A), SW14.2
unnamed: D15.1 (K), J101.1, J101.2
unnamed: D15.2 (A), SW15.2
unnamed: D16.1 (K), J103.1, J103.2
unnamed: D16.2 (A), SW16.2
unnamed: D17.1 (K), J102.1, J102.2
unnamed: D17.2 (A), SW17.2
unnamed: D18.1 (K), J7.7, J98.1
unnamed: D18.2 (A), SW18.2
unnamed: D19.1 (K), J93.1, J93.2
unnamed: D19.2 (A), SW19.2
unnamed: D20.1 (K), J94.1, J94.2
unnamed: D20.2 (A), SW20.2
unnamed: D21.1 (K), J95.1, J95.2
unnamed: D21.2 (A), SW21.2
unnamed: D22.1 (K), J96.1, J96.2
unnamed: D22.2 (A), SW23.2
unnamed: D23.1 (K), J97.1, J97.2
unnamed: D23.2 (A), SW22.2
unnamed: D24.1 (K), J7.6, J92.1
unnamed: D24.2 (A), SW24.2
unnamed: D25.1 (K), J87.1, J87.2
unnamed: D25.2 (A), SW25.2
unnamed: D26.1 (K), J89.1, J89.2
unnamed: D26.2 (A), SW27.2
unnamed: D27.1 (K), J88.1, J88.2
unnamed: D27.2 (A), SW26.2
unnamed: D28.1 (K), J90.1, J90.2
unnamed: D28.2 (A), SW29.2
unnamed: D29.1 (K), J91.1, J91.2
unnamed: D29.2 (A), SW28.2
unnamed: D30.1 (K), J7.5, J86.1
unnamed: D30.2 (A), SW30.2
unnamed: D31.1 (K), J82.1, J82.2
unnamed: D31.2 (A), SW31.2
unnamed: D32.1 (K), J83.1, J83.2
unnamed: D32.2 (A), SW32.2
unnamed: D33.1 (K), J84.1, J84.2
unnamed: D33.2 (A), SW33.2
unnamed: D34.1 (K), J85.1, J85.2
unnamed: D34.2 (A), SW36.2
unnamed: D35.1 (K), J81.1, J81.2
unnamed: D35.2 (A), SW34.2
unnamed: D36.1 (K), J80.1
unnamed: D36.2 (A), SW35.2
unnamed: D37.1 (K), J75.1, J75.2
unnamed: D37.2 (A), SW37.2
unnamed: D38.1 (K), J76.1, J76.2
unnamed: D38.2 (A), SW38.2
unnamed: D39.1 (K), J79.1, J79.2
unnamed: D39.2 (A), SW40.2
unnamed: D40.1 (K), J77.1, J77.2
unnamed: D40.2 (A), SW39.2
unnamed: D41.1 (K), J78.1, J78.2
unnamed: D41.2 (A), SW41.2
unnamed: D42.1 (K), J71.1, J71.2
unnamed: D42.2 (A), SW42.2
unnamed: D43.1 (K), J72.1, J72.2
unnamed: D43.2 (A), SW43.2
unnamed: D44.1 (K), J70.1
unnamed: D44.2 (A), SW45.2
unnamed: D45.1 (K), J73.1, J73.2
unnamed: D45.2 (A), SW44.2
unnamed: D46.1 (K), J69.1, J69.2
unnamed: D46.2 (A), SW46.2
unnamed: D47.1 (K), J68.1
unnamed: D47.2 (A), SW47.2
unnamed: D48.1 (K), R1.1
unnamed: D48.2 (A), J140.1
unnamed: D49.1 (K), R2.1
unnamed: D49.2 (A), J142.1
unnamed: D50.1 (K), R4.1
unnamed: D50.2 (A), J146.1
unnamed: D51.1 (K), R6.1
unnamed: D51.2 (A), J148.1
unnamed: D52.1 (K), R7.2
unnamed: D52.2 (A), J138.1
unnamed: D53.1 (K), R8.2
unnamed: D53.2 (A), J136.1
unnamed: D54.1 (K), R10.2
unnamed: D54.2 (A), J132.1
unnamed: D55.1 (K), R12.2
unnamed: D55.2 (A), J130.1
unnamed: D56.2 (A), SW50.2
unnamed: D57.1 (K), J66.1, J66.2
unnamed: D57.2 (A), SW51.2
unnamed: D58.1 (K), J64.1, J64.2
unnamed: D58.2 (A), SW54.2
unnamed: D59.1 (K), J63.1, J63.2
unnamed: D59.2 (A), SW53.2
unnamed: D60.1 (K), J62.1, J62.2
unnamed: D60.2 (A), SW52.2
unnamed: D61.2 (A), SW55.2
unnamed: D62.1 (K), J59.1, J59.2
unnamed: D62.2 (A), SW58.2
unnamed: D63.1 (K), J60.1, J60.2
unnamed: D63.2 (A), SW56.2
unnamed: D64.1 (K), J58.1, J58.2
unnamed: D64.2 (A), SW57.2
unnamed: D65.1 (K), J61.1, J61.2
unnamed: D65.2 (A), SW59.2
unnamed: D66.1 (K), J57.1, J57.2
unnamed: D66.2 (A), SW60.2
unnamed: D67.2 (A), SW65.2
unnamed: D68.1 (K), J51.1, J51.2
unnamed: D68.2 (A), SW62.2
unnamed: D69.1 (K), J52.1, J52.2
unnamed: D69.2 (A), SW63.2
unnamed: D70.1 (K), J53.1, J53.2
unnamed: D70.2 (A), SW61.2
unnamed: D71.1 (K), J54.1, J54.2
unnamed: D71.2 (A), SW64.2
unnamed: D72.1 (K), J50.1, J50.2
unnamed: D72.2 (A), SW66.2
unnamed: D73.1 (K), J45.1, J45.2
unnamed: D73.2 (A), SW69.2
unnamed: D74.1 (K), J47.1, J47.2
unnamed: D74.2 (A), SW67.2
unnamed: D75.1 (K), J48.1, J48.2
unnamed: D75.2 (A), SW71.2
unnamed: D76.2 (A), SW68.2
unnamed: D77.1 (K), J46.1, J46.2
unnamed: D77.2 (A), SW70.2
unnamed: D78.1 (K), J44.1, J44.2
unnamed: D78.2 (A), SW72.2
unnamed: D79.1 (K), J39.1, J39.2
unnamed: D79.2 (A), SW75.2
unnamed: D80.1 (K), J40.1, J40.2
unnamed: D80.2 (A), SW76.2
unnamed: D81.1 (K), J41.1, J41.2
unnamed: D81.2 (A), SW73.2
unnamed: D82.1 (K), J42.1, J42.2
unnamed: D82.2 (A), SW77.2
unnamed: D83.2 (A), SW74.2
unnamed: D84.1 (K), J38.1, J38.2
unnamed: D84.2 (A), SW78.2
unnamed: D85.1 (K), J25.1, J25.2
unnamed: D85.2 (A), SW79.2
unnamed: D86.2 (A), SW80.2
unnamed: D87.1 (K), J23.1, J23.2
unnamed: D87.2 (A), SW81.2
unnamed: D88.1 (K), J24.1, J24.2
unnamed: D88.2 (A), SW82.2
unnamed: D89.1 (K), J37.1, J37.2
unnamed: D89.2 (A), SW83.2
unnamed: D90.1 (K), J22.1, J22.2
unnamed: D90.2 (A), SW84.2
unnamed: D91.2 (A), SW86.2
unnamed: D92.1 (K), J17.1, J17.2
unnamed: D92.2 (A), SW87.2
unnamed: D93.1 (K), J18.1, J18.2
unnamed: D93.2 (A), SW88.2
unnamed: D94.1 (K), J19.1, J19.2
unnamed: D94.2 (A), SW85.2
unnamed: D95.1 (K), J20.1, J20.2
unnamed: D95.2 (A), SW89.2
unnamed: D96.1 (K), J16.1, J16.2
unnamed: D96.2 (A), SW90.2
unnamed: D97.2 (A), SW92.2
unnamed: D98.1 (K), J13.1, J13.2
unnamed: D98.2 (A), SW91.2
unnamed: D99.1 (K), J14.1, J14.2
unnamed: D99.2 (A), SW95.2
unnamed: D100.1 (K), J11.1, J11.2
unnamed: D100.2 (A), SW93.2
unnamed: D101.1 (K), J12.1, J12.2
unnamed: D101.2 (A), SW94.2
unnamed: D102.1 (K), J9.1, J9.2
unnamed: D102.2 (A), SW96.2
unnamed: H21.1, H27.1
unnamed: J7.3, J74.1
unnamed: J26.1, SW1.1, SW7.1, SW13.1, SW19.1, SW25.1, SW31.1, SW37.1
unnamed: J27.1, SW2.1, SW8.1, SW14.1, SW20.1, SW26.1, SW32.1, SW38.1, SW42.1
unnamed: J28.1, SW3.1, SW9.1, SW15.1, SW21.1, SW27.1, SW33.1, SW39.1, SW43.1
unnamed: J29.1, SW5.1, SW11.1, SW17.1, SW23.1, SW29.1, SW36.1, SW41.1
unnamed: J30.1, SW4.1, SW10.1, SW16.1, SW22.1, SW28.1, SW34.1, SW40.1, SW44.1
unnamed: J31.1, SW6.1, SW12.1, SW18.1, SW24.1, SW30.1
unnamed: J6.7, J56.1
unnamed: J117.1, SW50.1, SW55.1, SW65.1
unnamed: J119.1, SW51.1
unnamed: J120.1, SW46.1
unnamed: J121.1, SW35.1, SW45.1, SW47.1
unnamed: J122.1, SW49.2
unnamed: J6.6, J123.1
unnamed: J6.8, J124.1
unnamed: J6.9, J125.1
unnamed: J7.1, J126.1
unnamed: J7.2, J127.1
unnamed: J7.4, J128.1
unnamed: J133.1, R7.1, R8.1, R10.1, R12.1
unnamed: J143.1, R1.2, R2.2, R4.2, R6.2
unnamed: J149.1, U2.30 (RUN)
unnamed: J150.1, SW49.1
unnamed: J151.1, U1.30 (RUN)
unnamed: J152.1, SW48.1
unnamed: J153.1, SW48.2
PWM1: J129.1, U2.21 (GPIO16)
PWM1R: J147.1, U1.21 (GPIO16)
PWM2: J131.1, U2.22 (GPIO17)
PWM2R: J145.1, U1.22 (GPIO17)
PWM3: J135.1, U2.24 (GPIO18)
PWM3R: J141.1, U1.24 (GPIO18)
PWM4: J137.1, U2.25 (GPIO19)
PWM4R: J139.1, U1.25 (GPIO19)
ROW1: J3.1, U2.6 (GPIO4)
ROW1R: J10.1, U1.6 (GPIO4)
ROW2: J3.2, U2.7 (GPIO5)
ROW2R: J10.2, U1.7 (GPIO5)
ROW3: J3.3, U2.9 (GPIO6)
ROW3R: J10.3, U1.9 (GPIO6)
ROW4: J3.4, U2.10 (GPIO7)
ROW4R: J10.4, U1.10 (GPIO7)
ROW5: J3.5, U2.11 (GPIO8)
ROW5R: J10.5, U1.11 (GPIO8)
ROW6: J3.6, U2.12 (GPIO9)
ROW6R: J10.6, U1.12 (GPIO9)
SCL I2C0: J2.3, R11.1, U2.2 (GPIO1)
SDA I2C0: J2.2, R9.1, U2.1 (GPIO0)
VCCL: J2.4, R9.2, R11.2, U2.40 (VBUS)
VCCR: J1.4, R3.2, R5.2, U1.40 (VBUS)
sclR: J1.3, R3.1, U1.2 (GPIO1)
sdaR: J1.2, R5.1, U1.1 (GPIO0)

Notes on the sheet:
EG2614-ND
Keyswitch Hotswap sockets: 0305-2-15-80-47-80-10-0 or Digikey: ED90584-ND
CAPS
Right and left sides separated by blue lines.
Scroll
OMIT R9 R11 IF SERIAL COMM IS USED.
SPLIT_HAND_PIN_LOW_IS_LEFT
TRRS jack, SJ-43514

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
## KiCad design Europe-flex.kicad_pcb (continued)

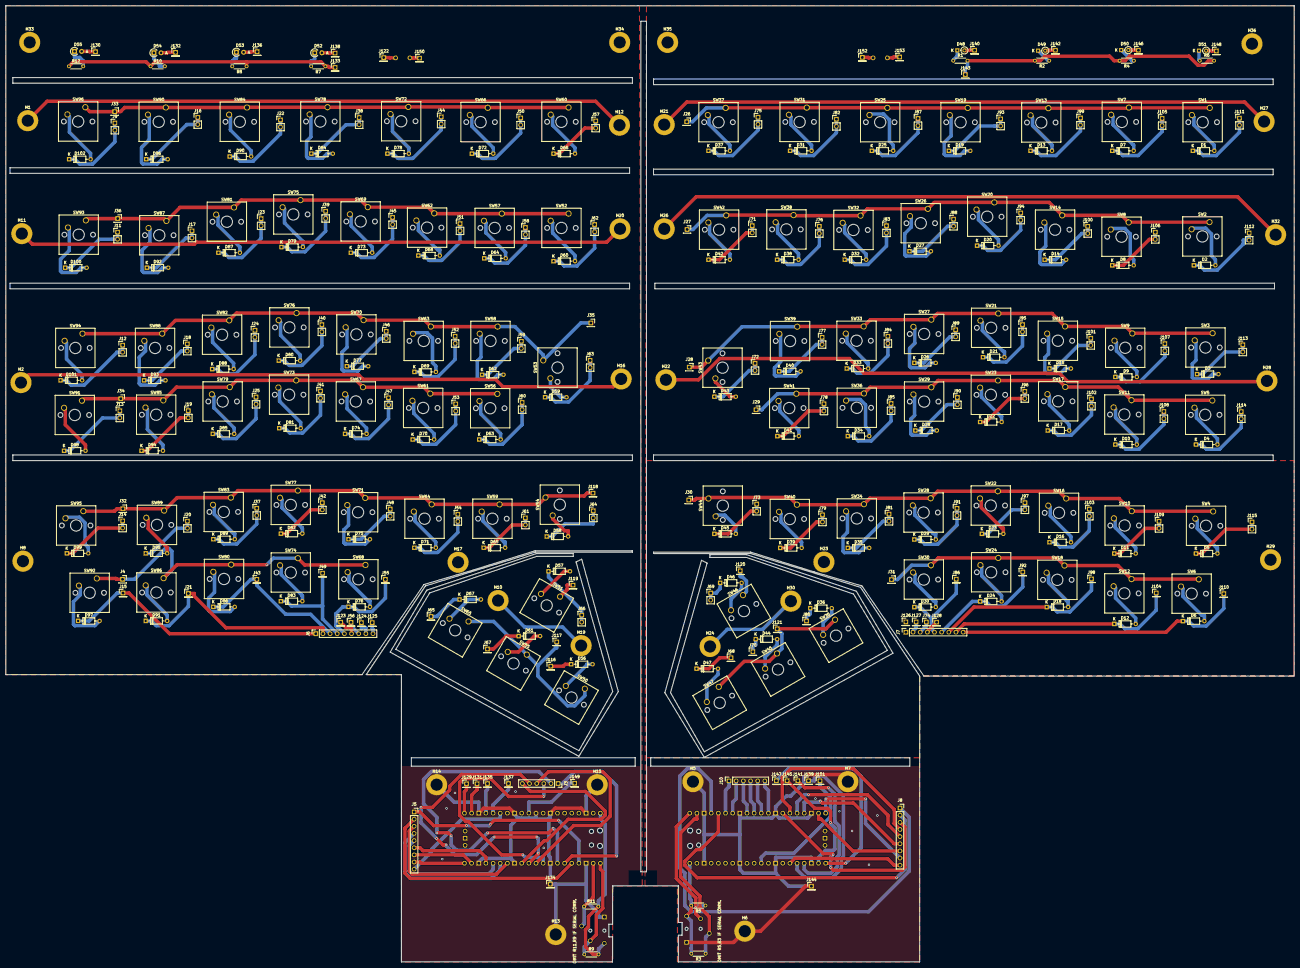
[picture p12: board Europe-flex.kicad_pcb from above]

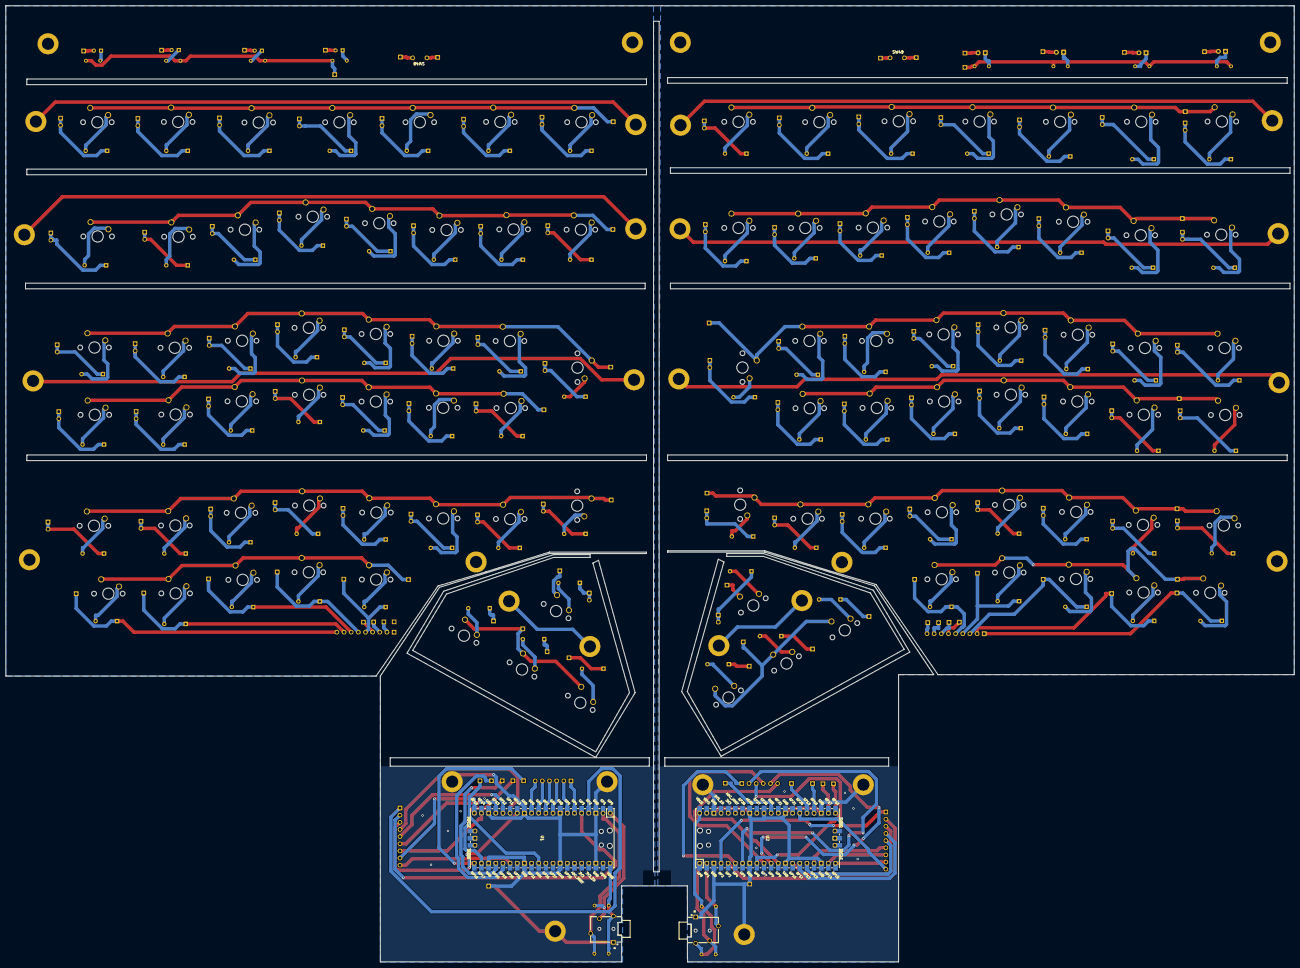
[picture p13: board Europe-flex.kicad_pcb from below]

Board: 2 copper layers, 457.5 x 339.5 mm, 395 parts (6 on the bottom side), 294 nets.

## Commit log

2022-12-20 Add files via upload
    added files.
    [Europe-flex-B_Cu.gbr, Europe-flex-B_Mask.gbr, Europe-flex-B_Paste.gbr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]
2022-12-24 Add files via upload
    fixed small routing issue
    [Europe-flex-B_Cu.gbr, Europe-flex-B_Mask.gbr, Europe-flex-B_Paste.gbr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]
2023-01-02 Add files via upload
    added files for 3D printing.
    [holder-left.stl, holder-right.stl, holder-thumb.stl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]
